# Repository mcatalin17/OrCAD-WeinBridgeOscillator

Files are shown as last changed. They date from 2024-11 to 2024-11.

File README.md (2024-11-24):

# OrCAD-WeinBridgeOscillator
OrCAD project of a Wein bridge oscillator. I successfully implemented this project I had initially designed and simulated in OrCAD

This project was made in year 3 of my university studies at Politehnica University of Bucharest @ Faculty of Electronics, Telecommunications and Information Technology

Unfortunately the documentation is in Romanian so browse at your own risk!

###
###
###

###
###
###
WhatsApp Image 2024-11-24 at 15 43 05

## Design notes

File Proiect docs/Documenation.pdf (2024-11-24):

## Universitatea “Politehnica” din București

FACULTATEA DE ELECTRONICĂ, TELECOMUNICAȚII ȘI TEHNOLOGIA INFORMAȚIEI

# Oscilator RC cu punte Wien

## Proiect 1

Student: Mirea Catalin

## Grupa: 431Db

2022-2023

## 1) Date de proiectare

- N=25
- Frecventa de oscilatie reglabila, fo intre 12.5 - 75kHz
- Sarcina la iesire RL: 25kΩ
- Valoarea varf la varf a oscilatiei la iesire - Vo: 0.533V
- Control automat al amplitudinii de oscilaţie realizat cu TEC-J;
- Domeniul temperaturilor de func ionare: 0-70C ț

## 2) Schema bloc a circuitului

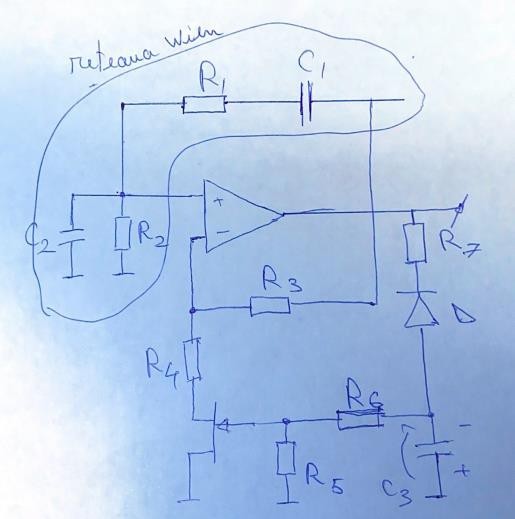
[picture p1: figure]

## f = 1/(2πRC)

osc
Se pot identifica urmatoarele blocuri componente:
- Amplificatorul de baza
- Reteaua de reactie pozitiva (Wien) (R1,R2,C1,C2)

## - Reteaua de reactie negativa (R3,R4,R5,R6,R7,D,TEC-J)

- Rezistenta de sarcina RL

## . 3) Schema oscilatorului

In figura se poate observa schema finala a oscilatorului. Acesta are in

componenta asa amplificatorul de baza si retelele de reactie.

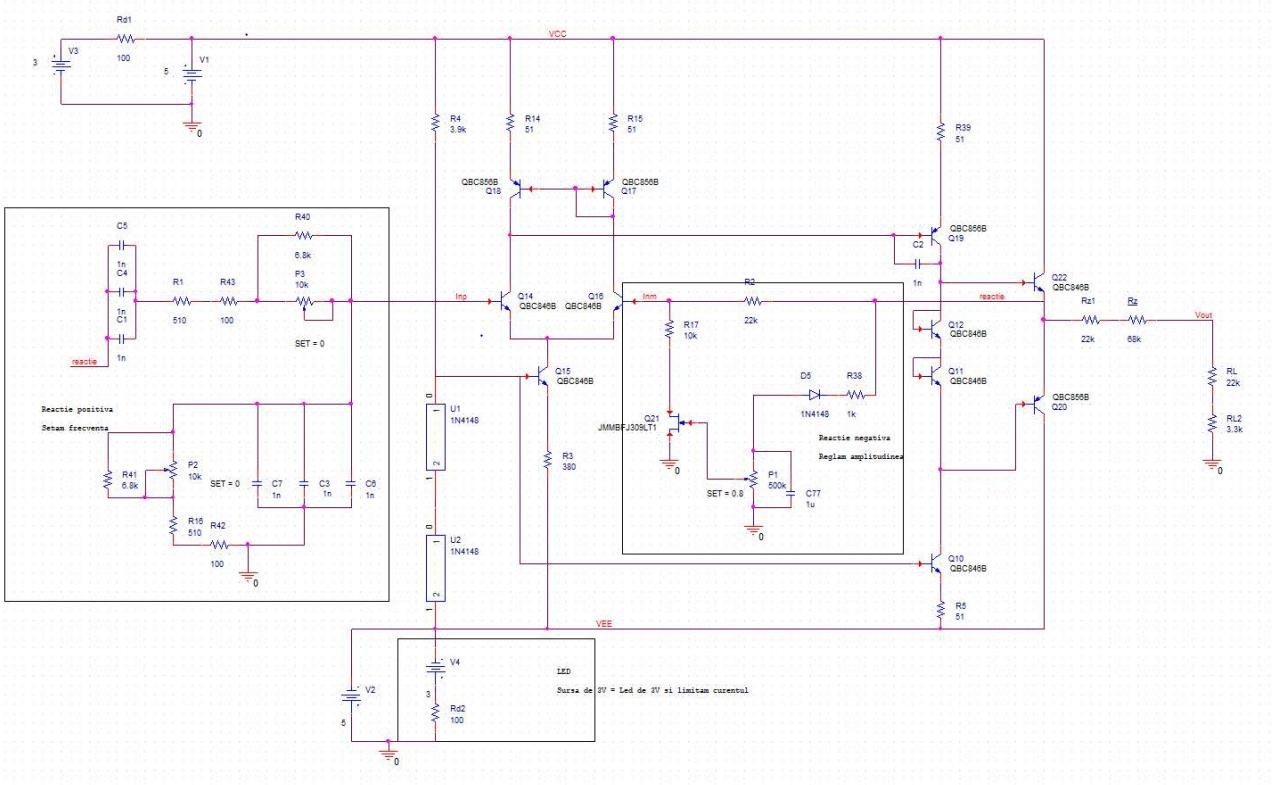
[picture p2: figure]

Blocurile componente ale oscilatorului sunt:

etaj diferential de intrare format din Q14 si Q16

Q2, Q3, Q4 surse de curent, pentru a stabili curentul prin ramuri

Q19 etaj de castig in conexiune emitor comun (etaj de amplificare)

C2 realizeaza compensare in frecventa (capacitate Miller)

P1 amorseaza oscilatiile

(P2 si P3) controleaza frecventa de oscilatie

## reteaua de reactie negative Q21, R17, R2, R38, D5, P1, C77

Q11 asigura reglaj cu ajutorul TEC-J

Q15 asigura current primului etaj de amplificare(Q14, Q16, Q17, Q18, R14,

R15)

Q10 asigura current celui de al doilea etaj de amplificare

## 5) Simularea oscilatorului

## 5.1) Punctul static de functionare calculat (teoretic)

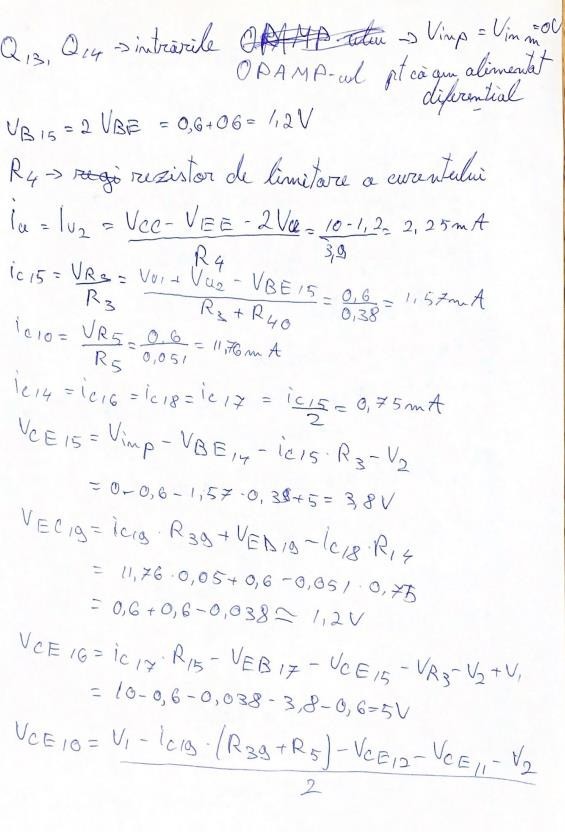
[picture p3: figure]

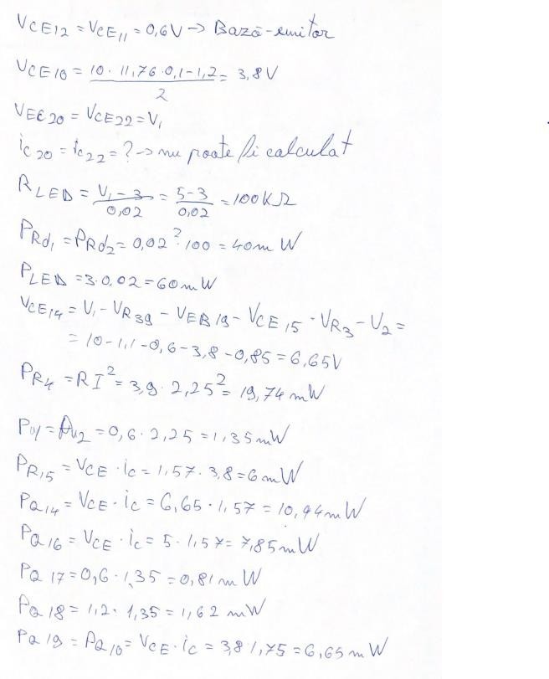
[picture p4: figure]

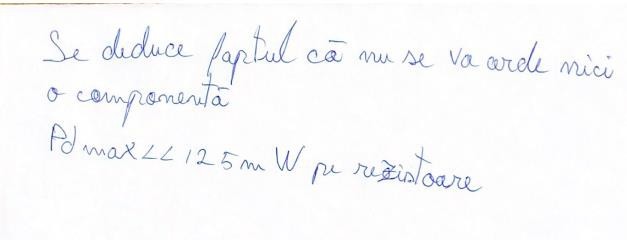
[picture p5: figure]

In figura de mai jos se pot observa curentii prin circuit, toti curentii fiind cei

asteptati in calcule.

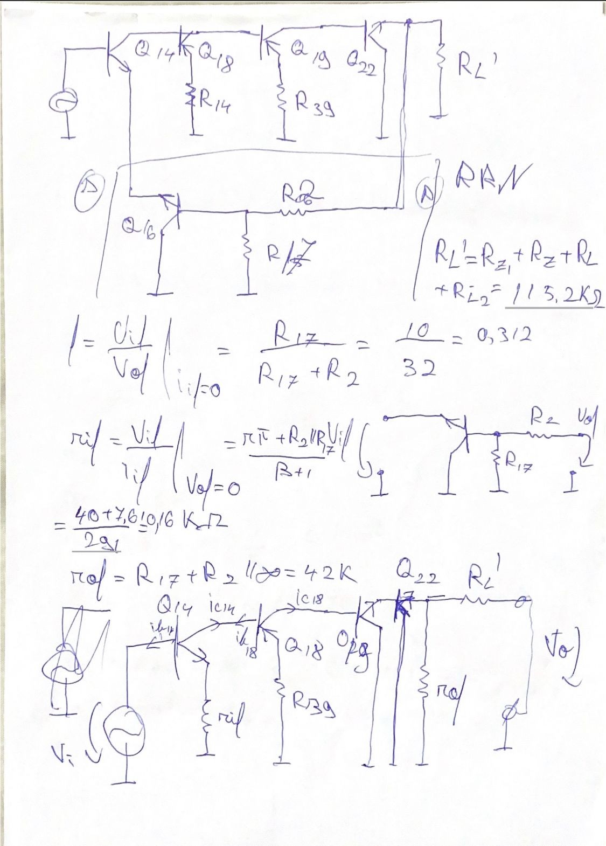
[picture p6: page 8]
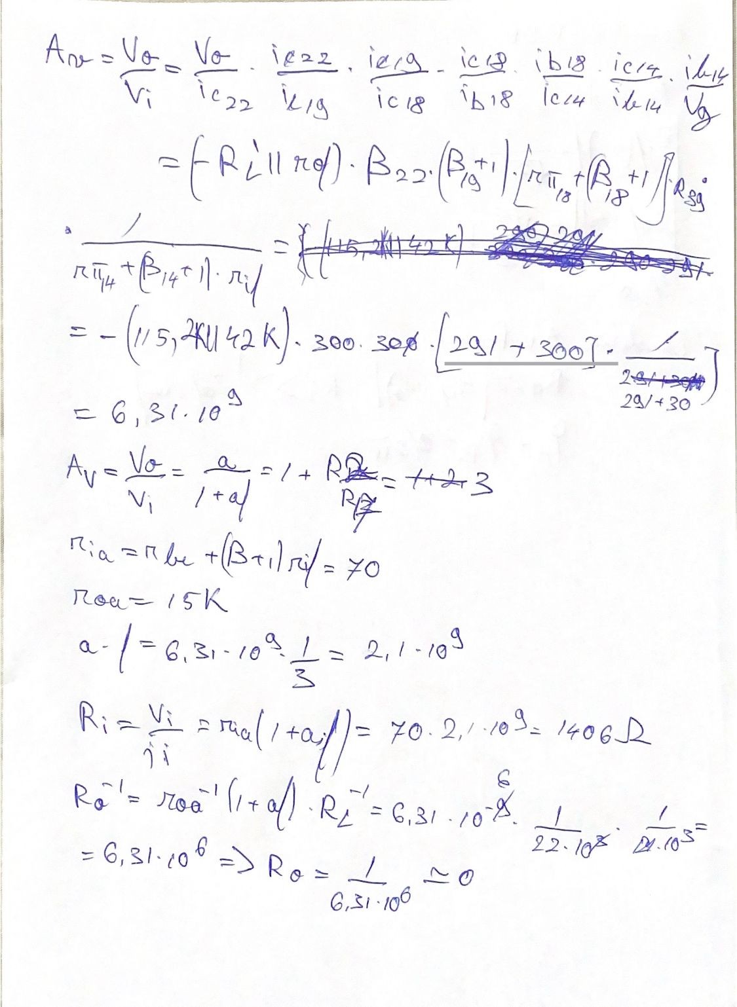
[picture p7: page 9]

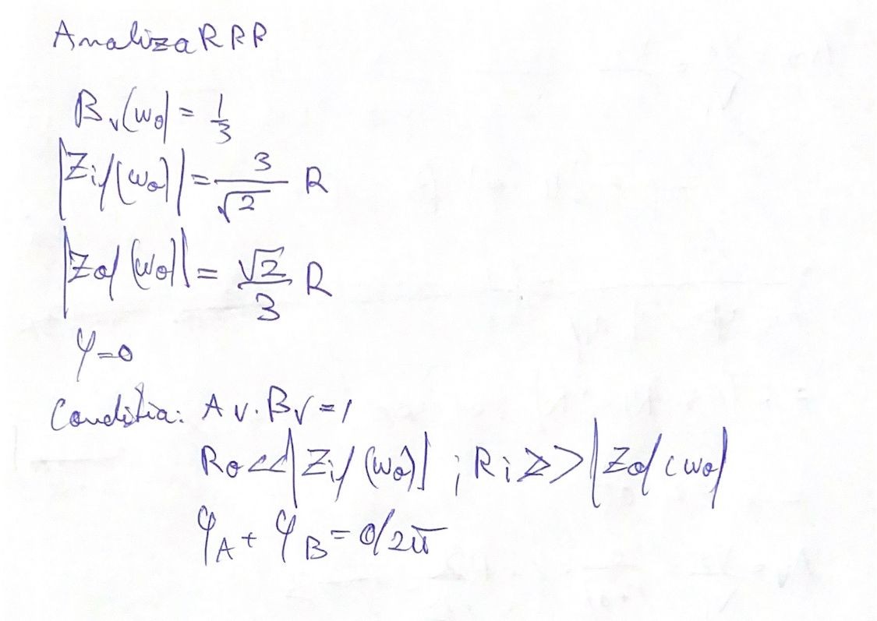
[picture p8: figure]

In figura de mai jos se pot observa curentii prin circuit, toti curentii fiind cei

asteptati in calcule.

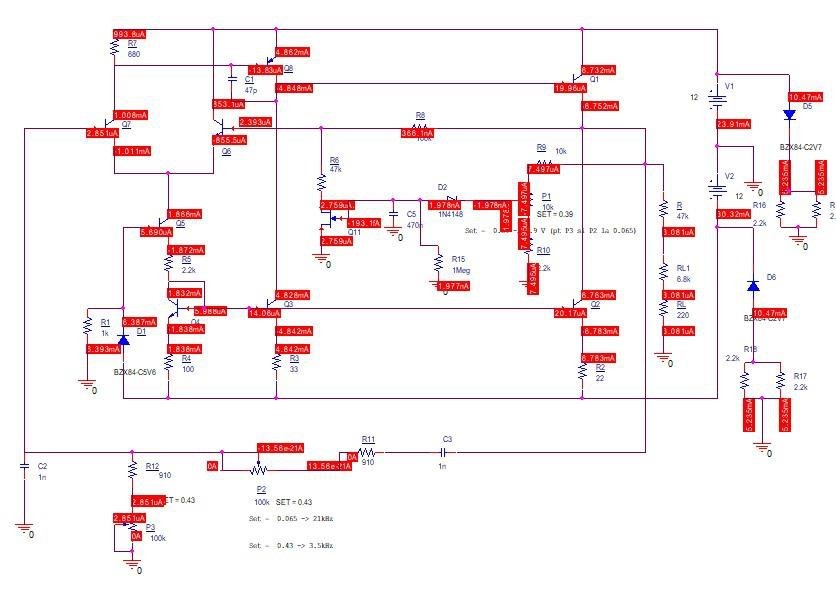
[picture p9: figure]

In figura de mai jos se pot observa tensiunile pe toate nodurile din circuit,

toate tranzistoarele bipolare fiind in RAN.

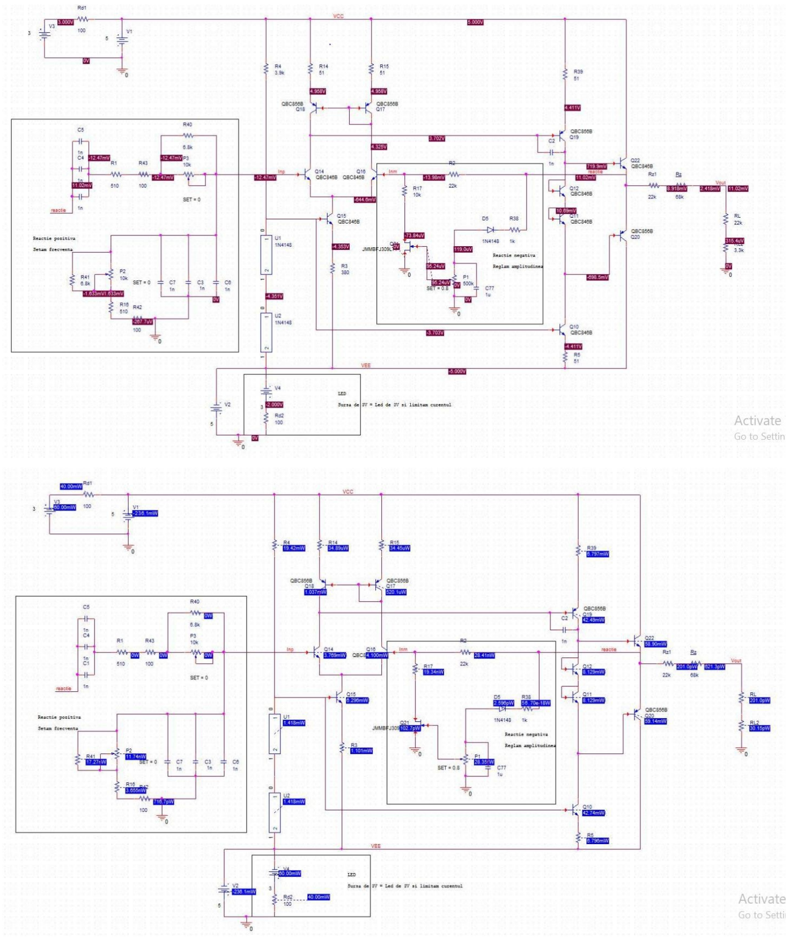
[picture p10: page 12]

## 5.5) Analiza in timp, transient

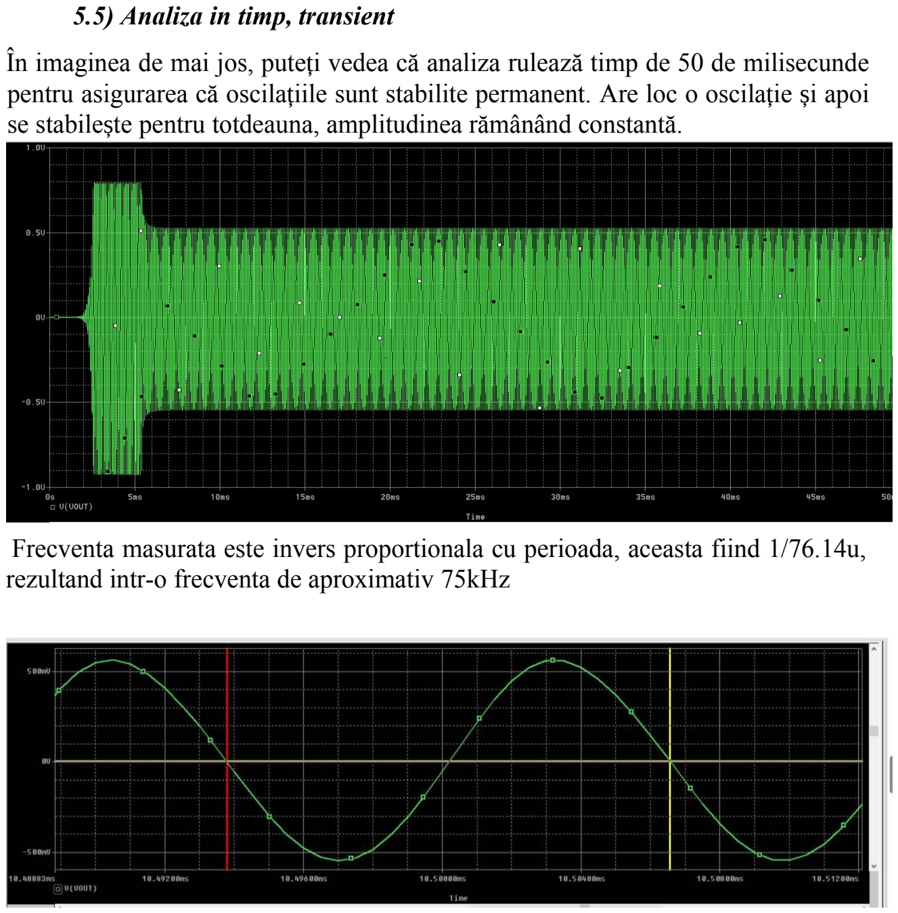
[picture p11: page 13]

În imaginea de mai jos, pute iț vedea că analiza rulează timp de 50 de milisecunde

pentru asigurarea că oscila iile ț | sunt stabilite permanent. Are loc o oscila ie ț și apoi

se stabile te ș pentru totdeauna, amplitudinea rămânând constantă.

Frecventa masurata este invers proportionala cu perioada, aceasta fiind 1/76.14u,

rezultand intr-o frecventa de aproximativ 75kHz

Se poate observa că circuitul este capabil să asigure o frecven ăț de oscila ieț în

intervalul specificat. Intervalul de temperatură de func ionare ț | este de la 0 la 70 de

grade Celsius. Analiza tranzitorie la diferite temperaturi este prezentată mai jos. Se

poate observa că oscilatorul asigură comportamentul dorit la toate valorile de

| temperatură

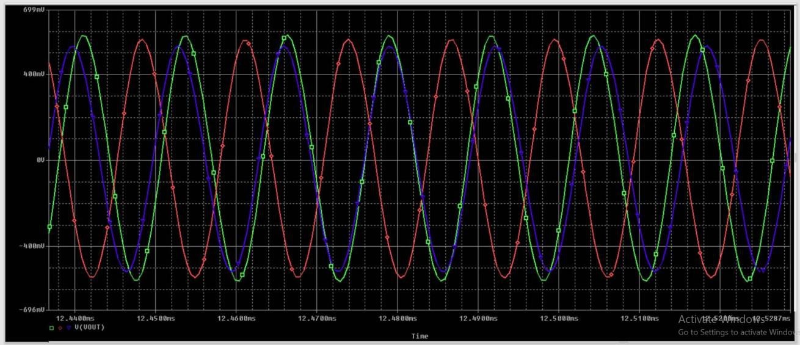
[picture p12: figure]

## 6) Layout

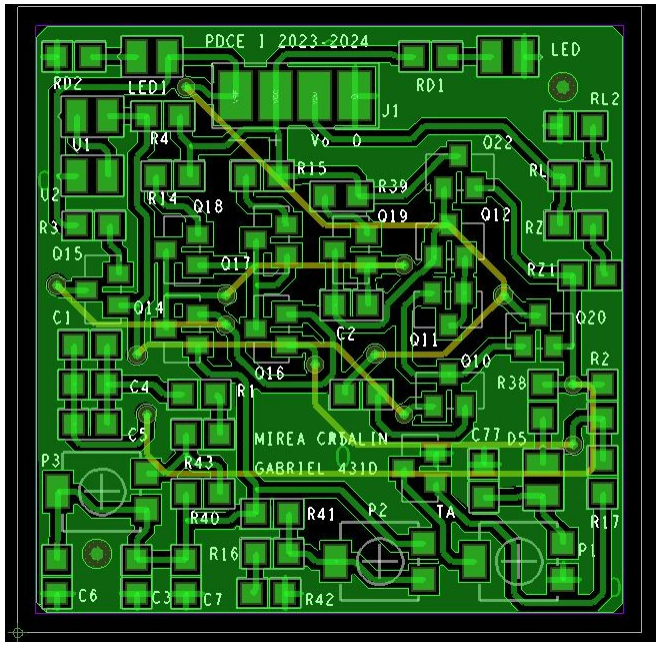
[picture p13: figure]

Pentru layout am folosit conectori in locul tensiunilor de alimentare si am

dimenstionat capsulele celorlalte componente conform data sheet.

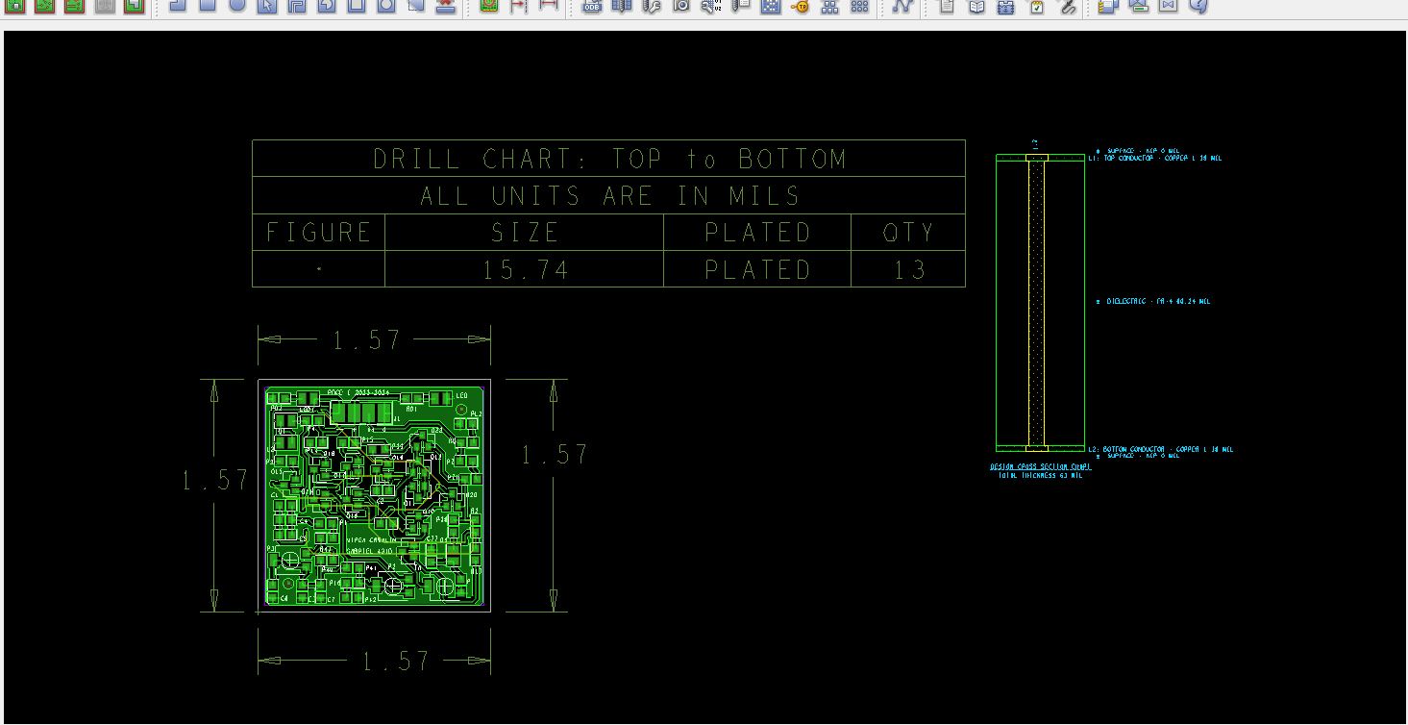
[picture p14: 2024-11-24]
Layout/Layoutss.JPG

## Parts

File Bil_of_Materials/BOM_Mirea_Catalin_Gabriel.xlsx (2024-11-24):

62 | 1nF | (LINK) (https://www.tme.eu/ro/details/cl21c102jbcnnnc/condensatoare-mlcc-smd-0805/samsung/) | CL21C102JBCNNNC | CL21C102JBCNNNC | SAMSUNG | condensator | 40 | 7 | Condensator MLCC, SMD, 0805, 1nF, ±5%, 50V, C0G | TME România | 0.06487 | 2.5948
73 | 1uF | (LINK) (https://www.tme.eu/ro/details/cl21b105kbfnnng/condensatoare-mlcc-smd-0805/samsung/) | CL21B105KBFNNNG | CL21B105KBFNNNG | SAMSUNG | condensator | 20 | 1 | Condensator: ceramic; MLCC; 1uF; 50V; X7R; ±20%; SMD; 0805 | TME România | 0.25253 | 5.0506
77 | 4148 | (LINK) (http://www.tme.eu/ro/details/1n4148-0805/diode-universale-smd/dc-components/cd4148ws0805c/) | 1N4148-0805 | CD4148WS(0805C) | DC Components | diodă pn | 50 | 3 | Diodă comutație, SMD, 0805, 300mA, 100V | TME România | 0.04555 | 2.2775
56 | 500k | (LINK) (http://www.tme.eu/ro/details/3314g-1-504e/trimere-smd-cu-o-singura-tura/bourns/) | 3314G-1-504E | 3314G-1-504E | BOURNS | potențiometru | 10 | 1 | Potențiome-tru liniar, simplă tură, SMD, 500kΩ, ±10%, 100ppm/°C, 0.25W | TME România | 2.8802 | 28.802
53 | 10k | (LINK) (http://www.tme.eu/ro/details/3314g-1-103e/trimere-smd-cu-o-singura-tura/bourns/) | 3314G-1-103E | 3314G-1-103E | BOURNS | potențiometru | 30 | 2 | Potențiome-tru liniar, simplă tură, SMD, 10kΩ, ±20%, 100ppm/°C, 0.25W | TME România | 3.0573 | 91.719
33 | 10k | (LINK) (https://www.tme.eu/ro/details/smd0805-10k/rezistente-smd-0805/royal-ohm/0805s8j0103t5e/) | SMD0805-10K-5% | 0805S8J0103T5E | ROYAL OHM | rezistor | 100 | 1 | Rezistor SMD, chip, 0805, 10kΩ, ±5%, 0.125W | TME România | 0.01723 | 1.723
87 | NPN | (LINK) (https://www.tme.eu/ro/details/bc846b-dio/tranzistori-smd-npn/diotec-semiconductor/bc846b/) | BC846B | BC846B | DIOTEC | tranzistor bipolar | 100 | 7 | Tranzistor bipolar NPN, SMD, SOT23, 65V, 100mA | TME România | 0.03379 | 3.379
86 | PNP | (LINK) (http://www.tme.eu/ro/details/bc856b-dio/tranzistori-smd-pnp/diotec-semiconductor/bc856b/) | BC856B | BC856B | DIOTEC | tranzistor bipolar | 100 | 4 | Tranzistor bipolar PNP, SMD, SOT23, 80V, 100mA | TME România | 0.04055 | 4.055
89 | N-JFET | (LINK) (http://www.tme.eu/ro/details/mmbfj309lt1g/tranzistori-canal-n-smd/on-semiconductor/) | MMBFJ309LT1G | MMBFJ309LT1G | ON Semiconductor | tranzistor NJFET | 50 | 1 | Tranzistor N-JFET, SMD, SOT23, 25V, 30mA | TME România | 0.8063 | 40.315
35 | 22k | (LINK) (https://www.tme.eu/ro/details/smd0805-22k/rezistente-smd-0805/royal-ohm/0805s8j0223t5e/) | SMD0805-22K-5% | 0805S8J0223T5E | ROYAL OHM | rezistor | 30 | 3 | Rezistor SMD, chip, 0805, 22kΩ, ±5%, 0.125W | TME România | 0.01723 | 0.5169
26 | 3.3k | (LINK) (https://www.tme.eu/ro/details/smd0805-3k3/rezistente-smd-0805/royal-ohm/0805s8j0332t5e/) | SMD0805-3K3-5% | 0805S8J0332T5E | ROYAL OHM | rezistor | 30 | 1 | Rezistor SMD, chip, 0805, 3.3kΩ, ±5%, 0.125W | TME România | 0.01723 | 0.5169
11 | 100 | (LINK) (https://www.tme.eu/ro/details/smd0805-100r/rezistente-smd-0805/royal-ohm/0805s8j0101t5e/) | SMD0805-100R-5% | 0805S8J0101T5E | ROYAL OHM | rezistor | 60 | 4 | Rezistor SMD, chip, 0805, 100Ω, ±5%, 0.125W | TME România | 0.01723 | 1.0338
37 | 68k | (LINK) (https://www.tme.eu/ro/details/smd0805-68k/rezistente-smd-0805/royal-ohm/0805s8j0683t5e/) | SMD0805-68K-5% | 0805S8J0683T5E | ROYAL OHM | rezistor | 20 | 1 | Rezistor SMD, chip, 0805, 68kΩ, ±5%, 0.125W | TME România | 0.01723 | 0.3446
16 | 510 | (LINK) (https://www.tme.eu/ro/details/smd0805-510r/rezistente-smd-0805/royal-ohm/0805s8j0511t5e/) | SMD0805-510R-5% | 0805S8J0511T5E | YAGEO | rezistor | 30 | 2 | Rezistor SMD, chip, 0805, 510Ω, ±5%, 0.125W | TME România | 0.01723 | 0.5169
27 | 3.9k | (LINK) (https://www.tme.eu/ro/details/smd0805-3k9/rezistente-smd-0805/royal-ohm/0805s8j0392t5e/) | SMD0805-3K9-5% | 0805S8J0392T5E | ROYAL OHM | rezistor | 20 | 1 | Rezistor SMD, chip, 0805, 3.9kΩ, ±5%, 0.125W | TME România | 0.01723 | 0.3446
8 | 51 | (LINK) (http://www.tme.eu/ro/details/rc0805jr-0751r/rezistente-smd-0805/yageo/rc0805jr-0751rl/) | SMD0805-51R-5% | 0805S8J0510T5E | ROYAL OHM | rezistor | 40 | 4 | Rezistor SMD, chip, 0805, 51Ω, ±5%, 0.125W | TME România | 0.0261 | 1.044
20 | 1k | (LINK) (https://www.tme.eu/ro/details/smd0805-1k/rezistente-smd-0805/royal-ohm/0805s8j0102t5e/) | SMD0805-1K-5% | 0805S8J0102T5E | ROYAL OHM | rezistor | 100 | 1 | Rezistor SMD, chip, 0805, 1kΩ, ±5%, 0.125W | TME România | 0.01723 | 1.723
30 | 6.8k | (LINK) (https://www.tme.eu/ro/details/rc0805jr-076k8/rezistente-smd-0805/yageo/rc0805jr-076k8l/) | SMD0805-6K8-5% | RC0805JR-076K8L | YAGEO | rezistor | 20 | 2 | Rezistor SMD, chip, 0805, 6.8kΩ, ±5%, 0.125W | TME România | 0.0261 | 0.522

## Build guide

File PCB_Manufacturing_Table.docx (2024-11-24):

General info document for PCB manufacturing
No. | Item Name | File Name | | | | | | Info / Remarks / Notes
| BOARD
s1 | Board Name / Number | LAYOUT.brd | | | | | | -
2 | Revision Date | 9 DEC 2023 | | | | | | -
3 | Board Size | 40 x 40 mm² | | | | | | -
4 | Board Quantity | 1 | | | | | | -
5 | Material / Dielectric Type | FR4 | | | | | | -
6 | Board Thickness | 1.6 mm | | | | | | -
7 | Copper Thickness | 35 μm | | | | | | -
| LAYERS
8 | Number of Electrical Layers | 2 | | | | | | -
9 | Copper Layer TOP | TOP.art | | | | | | -
10 | Copper Layer BOTTOM | BOTTOM.art | | | | | | -
11 | Copper GND Plane | - | | | | | | -
12 | Copper PWR Plane | - | | | | | | -
13 | Copper INNER 1 | - | | | | | | -
14 | Copper INNER 2 | - | | | | | | -
15 | Solder Mask TOP | SMTOP.art | | | | | | -
16 | Solder Mask BOTTOM | SMBOT.art | | | | | | -
17 | Solder Paste TOP | SPTOP.art | | | | | | -
18 | Solder Paste BOTTOM | - | | | | | | -
19 | Peelable Mask TOP | - | | | | | | -
20 | Peelable Mask BOTTOM | - | | | | | | -
21 | Silk Screen TOP | SSTOP.art | | | | | | -
22 | Silk Screen BOTTOM | - | | | | | | -
23 | Board Outline | BO.art | | | | | | -
24 | Fabrication Drawing | FAB.art | | | | | | -
| MILLING & DRILLING
25 | Mill Drawing | - | | | | | | -
26 | Drill Drawing | - | | | | | | -
27 | N.C. Drill (for both PH & NPH) | DRILL.drl | | | | | | -
28 | N.C. Drill / Plated Holes (PH) | 13 | | | | | | -
29 | N.C. Drill / Non-Plated Holes (PH) | - | | | | | | -
| FINISHING
30 | Panelisation | - | | | | | | -
31 | Electrical Test | - | | | | | | -
32 | Copper Finishing | x | HASL | | OSP | | | ENIG
33 | Board Outline Machining | | Routing | | Milling | | x | V-Cutting
34 | Final remarks | - | | | | -
